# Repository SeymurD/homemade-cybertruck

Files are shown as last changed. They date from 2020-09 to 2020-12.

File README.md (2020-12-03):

# Homemade CyberTruck

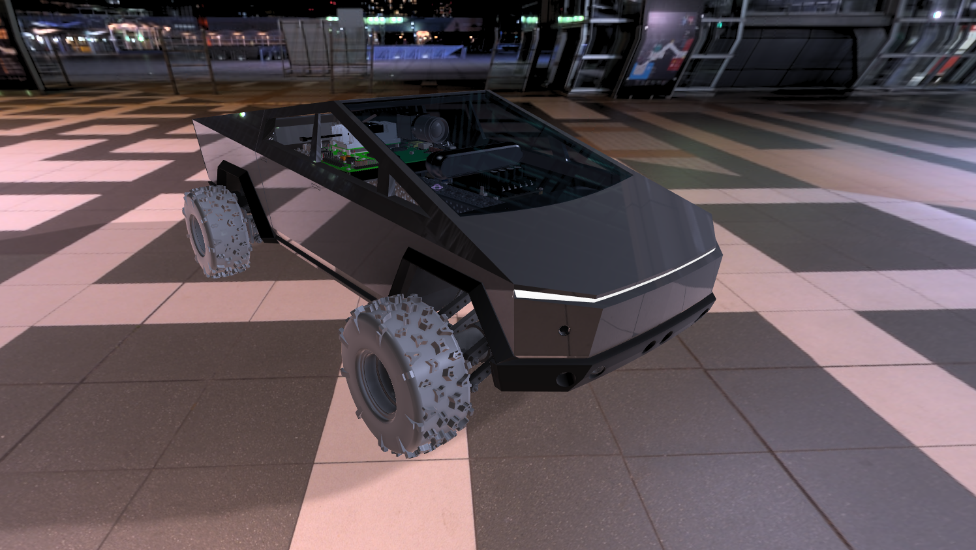
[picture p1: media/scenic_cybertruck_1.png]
CyberTruck Scene 1


### Introduction

The inspiration to build my own small replica of the Cybertruck was fueled by the shear want of trying to create something myself from the ground up and test myself to make something fun and exciting. Having worked on robots for a while in University project teams, I wanted to invest some money into my own maker gear such as a 3D printer, soldering stations, oscilloscope and all the small electronics to make this machine come to life.

The following will be a log of how my work on this progresses on starting from the model crafted in Fusion 360. As of now, I have probably spent around 1 1/2 months sizing, sketching and modelling the truck to be as close in proportion and stance as the real world beast. The greatest challenge in designing the shell of this vehicle is working both with the restrcition on my 3D printer in terms of accuracy, build volume, and part complexity such that I don't have overhangs present in every part. The chassis of was built from aluminium U-Channel beam for structural rigidity and stretches 24" in length. The length is actually closer to 28" when taking into the account the 3D printed rear end. The images below capture the overall design and placement of the interals using some of the rendering tools provided in Fusion360.

| | |
|:---:|:---:|
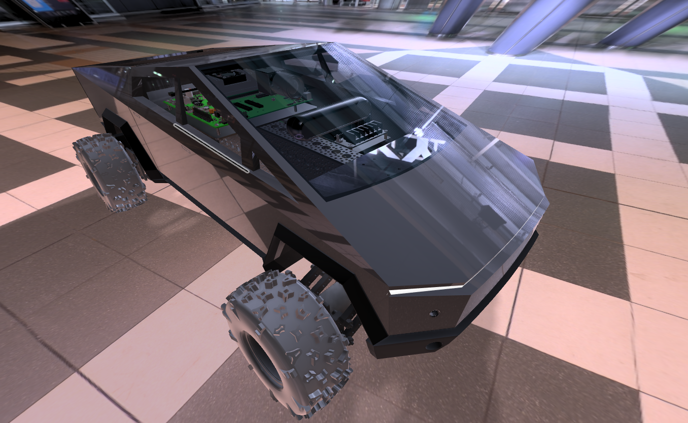
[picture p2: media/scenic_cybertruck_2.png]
cybertruck scene 2
|cybertruck scene 1  Three-Quarter Side View |   Elevated Side View|
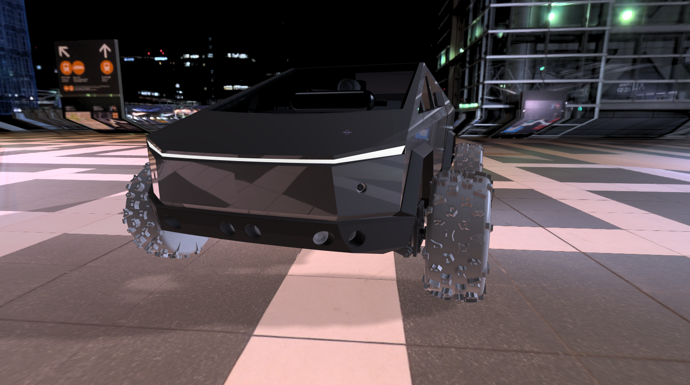
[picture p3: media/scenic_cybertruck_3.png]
cybertruck scene 3
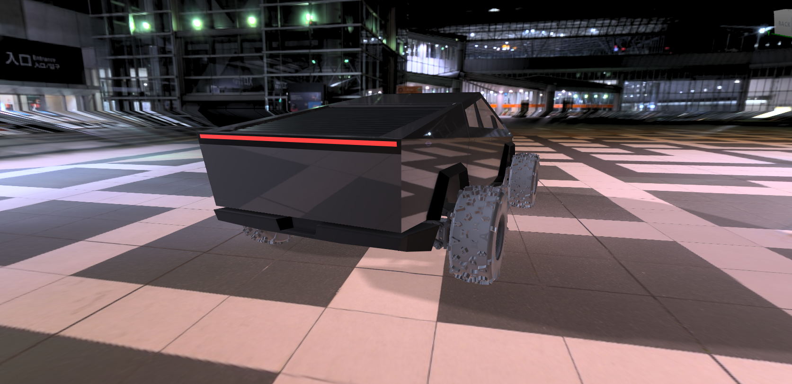
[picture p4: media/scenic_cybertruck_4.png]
cybertruck scene 4
| Front View |   Rear View|

From the Front View image, you may be wondering what some of the little holes are within the front bumper. The smaller holes on the silver portion are angled at 40-degrees and contain RaspberryPi Cam V2 with the base lens and serve as additional sources of imaging data that I can sync with the main FLIR BlackFlyS camera mounted high in the center of the vehicle. Additionally an Intel RealSense depth camera will be mounted near the dash space of the vehicle to provide depth information and once again will be synced with the main camera such that an image from the main camera can have a corresponding depth parameter.

On the lower black front bumper are 6 large holes that correspond to 3 ultrasonic sensors that most electronic hobbyists are familiar with: the HC-SR04 ultrasonic sensor!

The sensors are fitted snug inside the front section by having created a small pocket for each sensor which can be easily accessed in the wheel-well of the vehicle. A solution for keeping the internal wiring clean was also provided by having 3D printed channels run seamlessly within the body of the vehicle and taking advantage of the fact that the core of the vehicle is an aluminium channel.

| | |
|:---:|:---:|
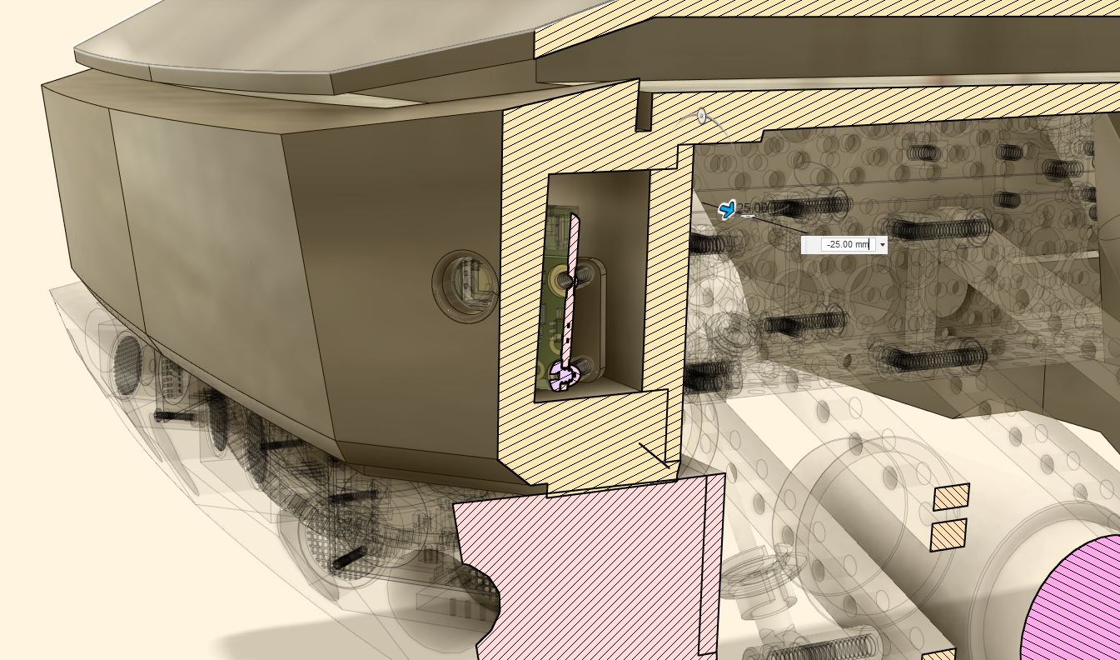
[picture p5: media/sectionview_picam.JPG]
cybertruck picam 1
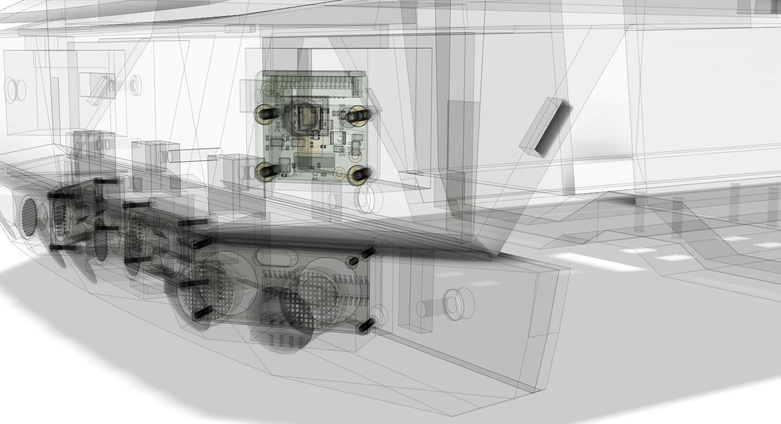
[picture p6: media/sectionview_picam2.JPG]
cybertruck picam 2
|  Cross-Sectional View |   Skeleton/Wireframe View|

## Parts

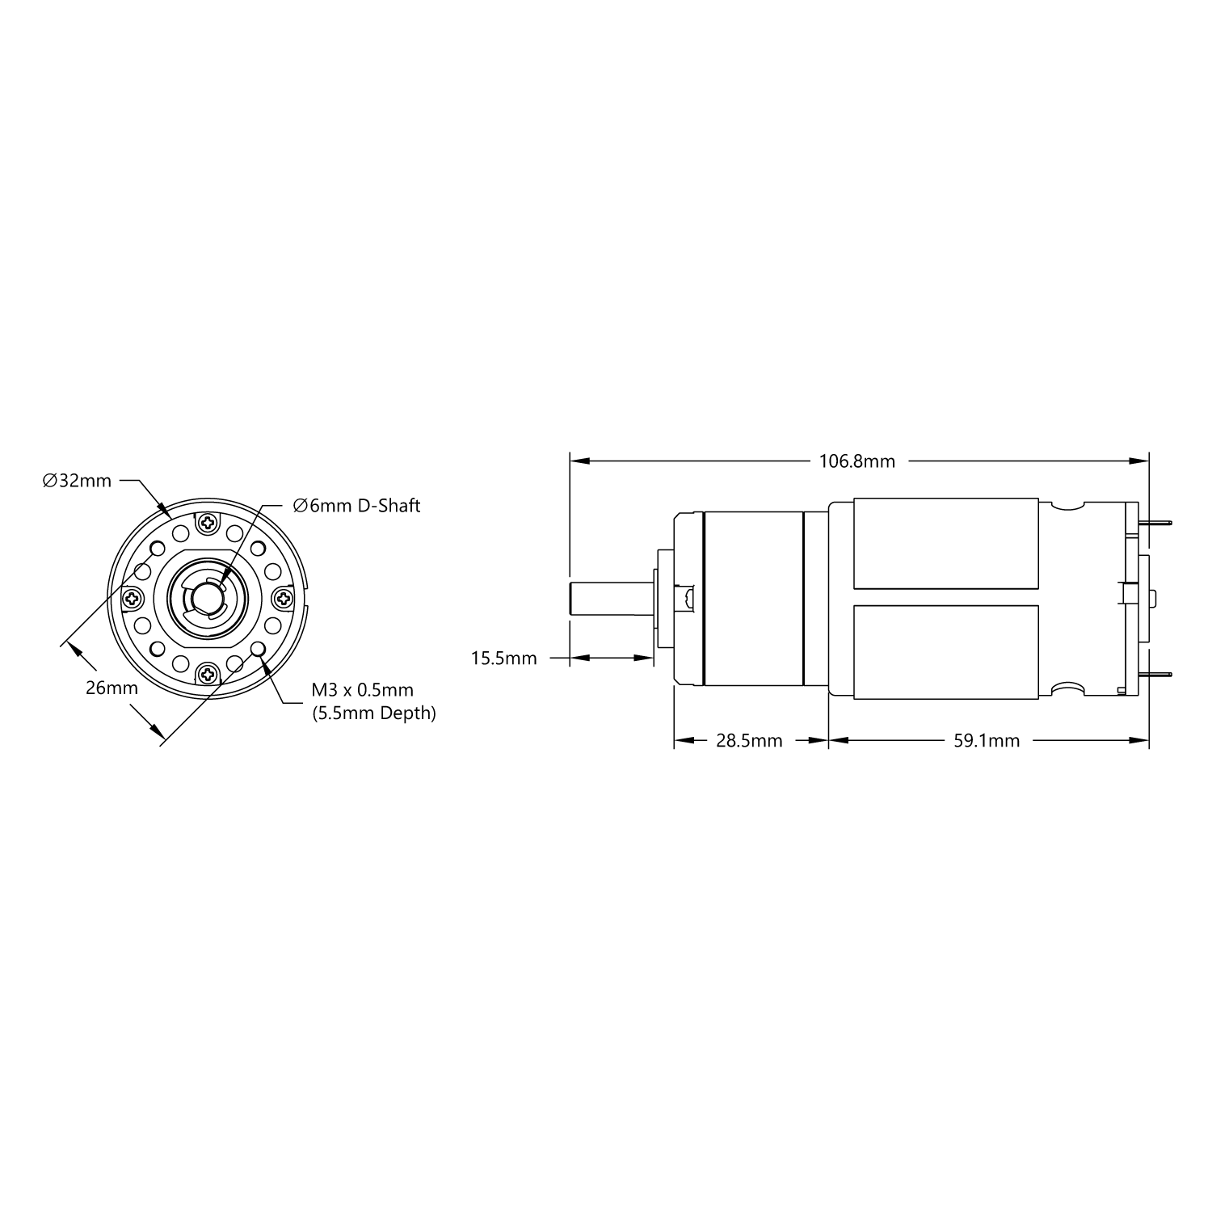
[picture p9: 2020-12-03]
Cybertruck Models/models/Chassis Parts/313 RPM Planetary Motor - CAD Drawing.png

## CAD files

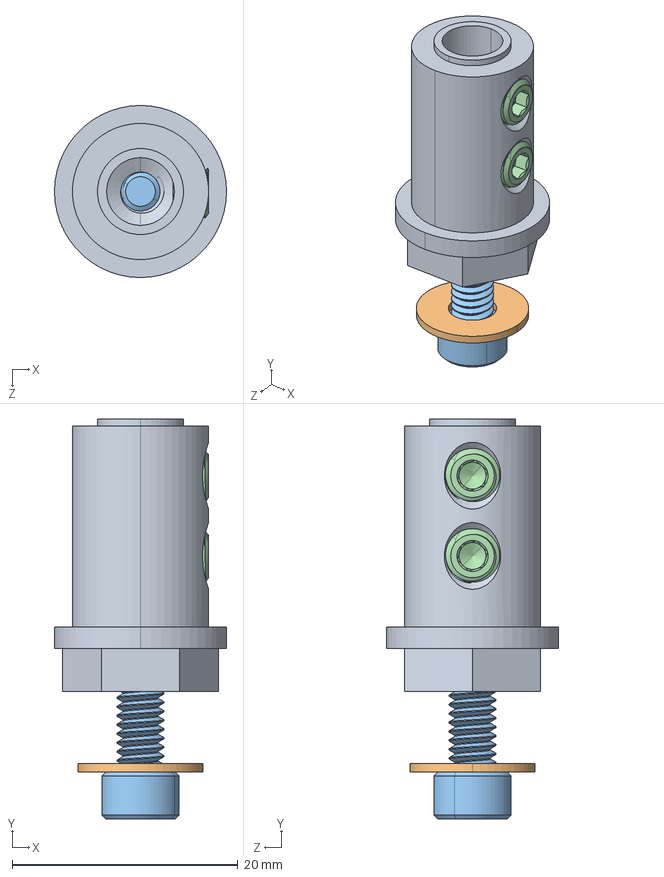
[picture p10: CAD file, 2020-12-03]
Cybertruck Models/models/Chassis Parts/6mm_bore_12mm_hexwheel_mount.STEP
15.2 x 35.4 x 15.2 mm
90126A009_90126A009
90128A194_90128A194
632134_91375A436 x 2

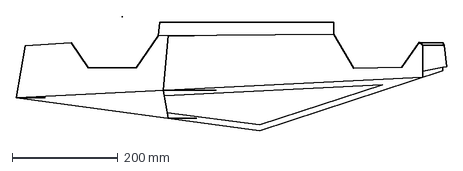
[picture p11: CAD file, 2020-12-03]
Cybertruck Models/models/Exterior Design/diagram_side.dxf
815.0 x 216.4 mm

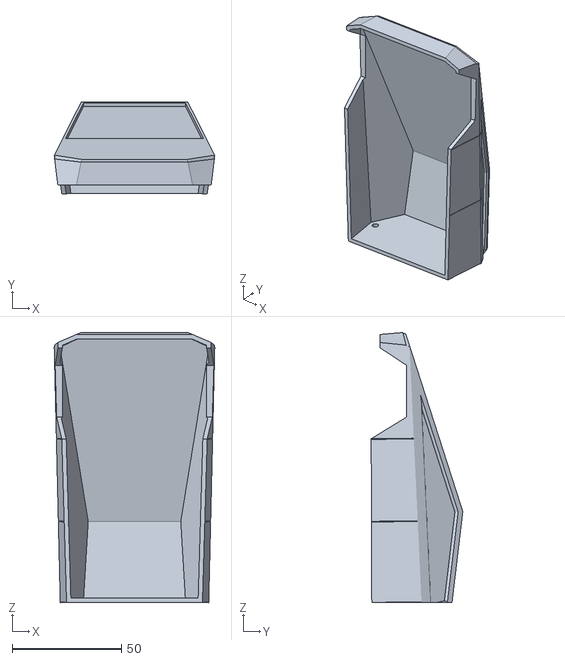
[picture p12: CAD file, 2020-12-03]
Cybertruck Models/models/Exterior Design/files/silver_body_front.stl
73.6 x 42.0 x 123.7

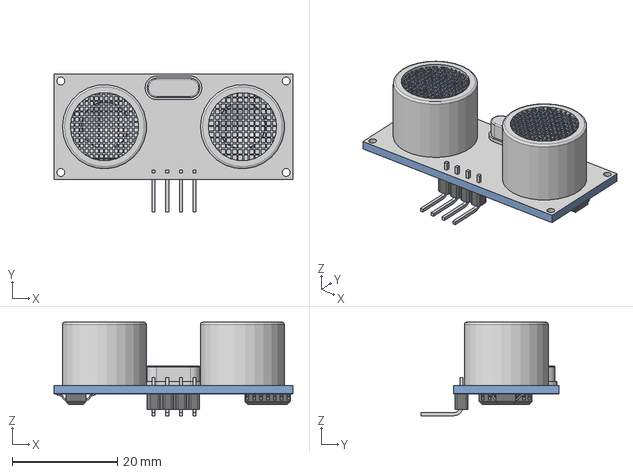
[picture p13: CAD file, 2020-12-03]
Cybertruck Models/models/Hardware Models/HC-SR04-UltrasonicSensor v7.step
45.5 x 26.2 x 17.8 mm

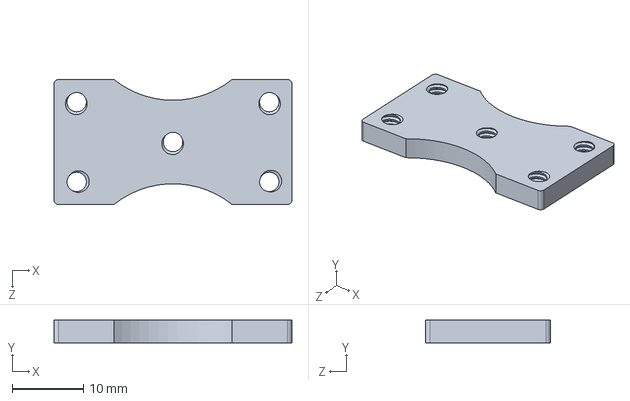
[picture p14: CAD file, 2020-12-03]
Cybertruck Models/models/Chassis Parts/channel_connector_plates.STEP
33.3 x 3.18 x 17.5 mm

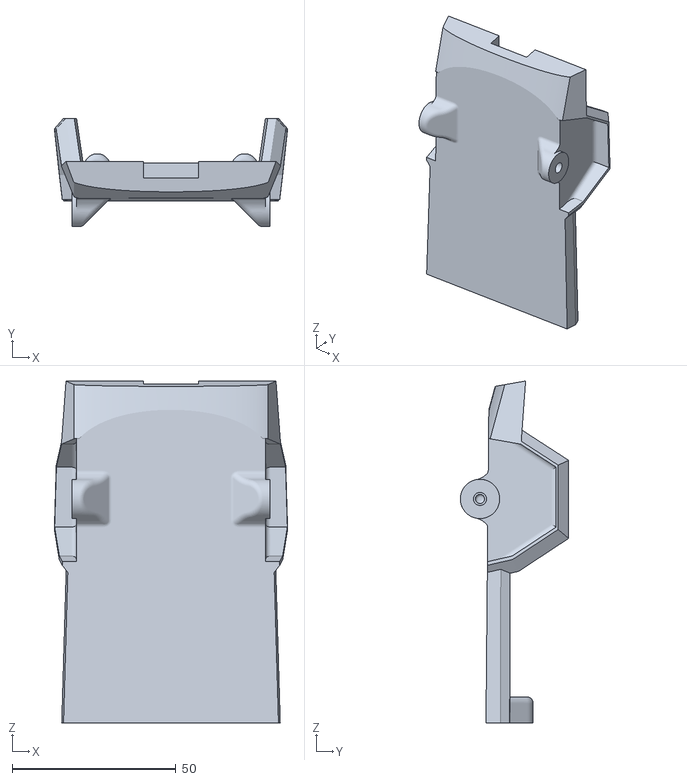
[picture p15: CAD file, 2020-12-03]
Cybertruck Models/models/Exterior Design/files/black_chassis_rear.stl
71.2 x 33.1 x 104.4

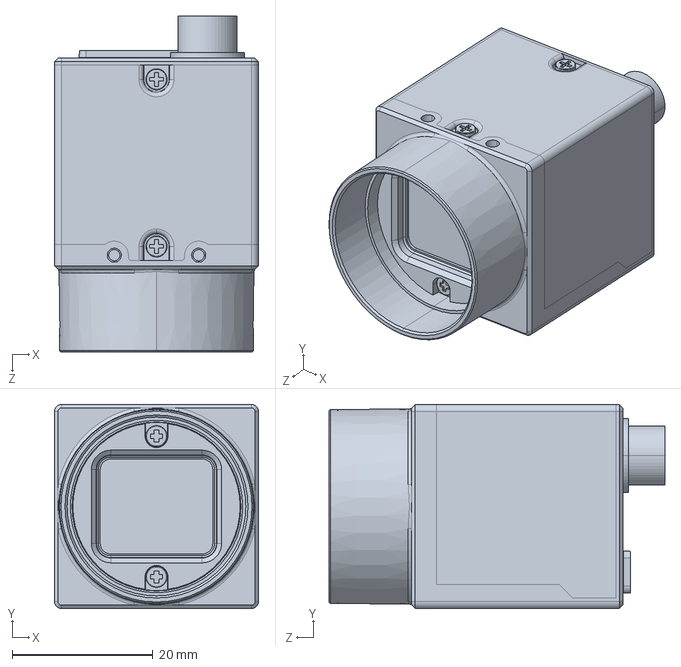
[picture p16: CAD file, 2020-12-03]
Cybertruck Models/models/Hardware Models/FL2-020-R0.STEP
29.0 x 29.0 x 47.8 mm

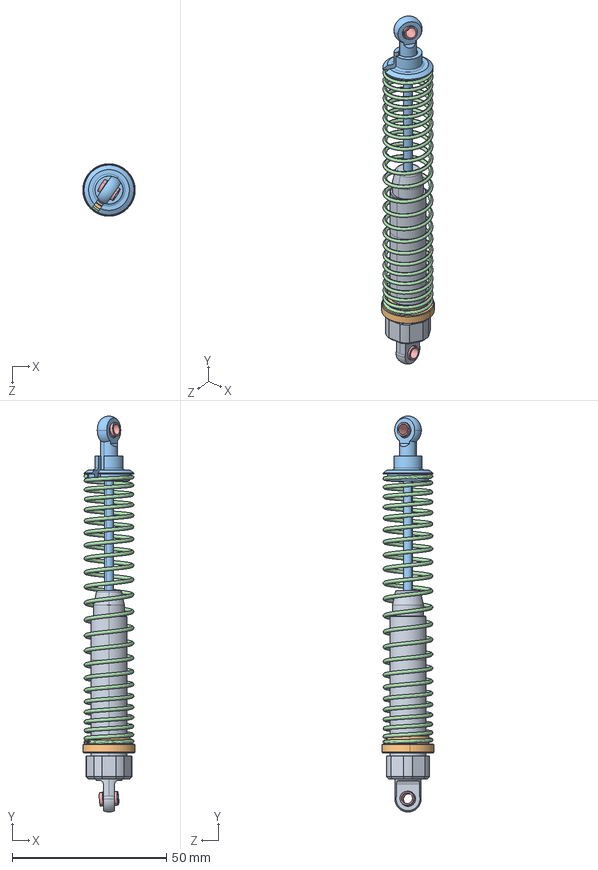
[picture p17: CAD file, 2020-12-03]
Cybertruck Models/models/Chassis Parts/robot_shocks.STEP
17.0 x 128.4 x 17.0 mm
585032 shock body
585032 shock collar
585032 shock shaft
585032 shock spring
585032 shock ball x 2

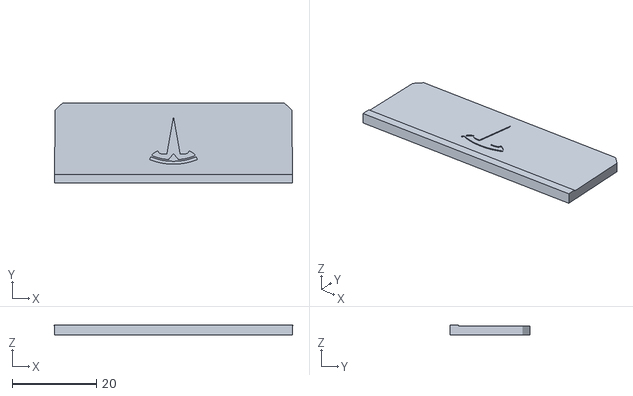
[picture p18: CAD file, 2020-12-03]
Cybertruck Models/models/Exterior Design/files/silver_rear_hatch.stl
56.8 x 19.0 x 2.38

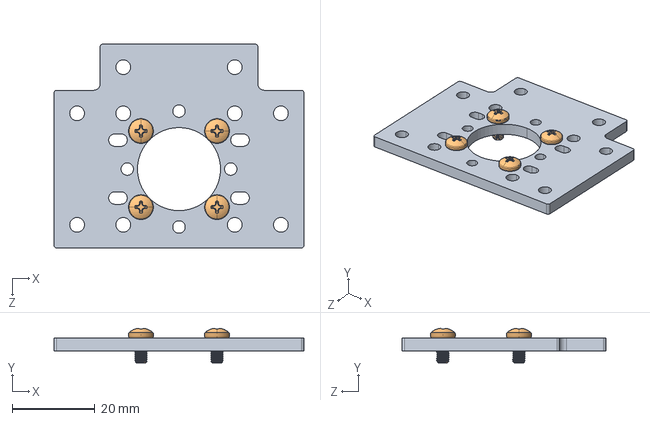
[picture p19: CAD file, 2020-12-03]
Cybertruck Models/models/Chassis Parts/motor_mount_d.STEP
60.4 x 8.34 x 49.3 mm
92005A116_92005A116 x 4

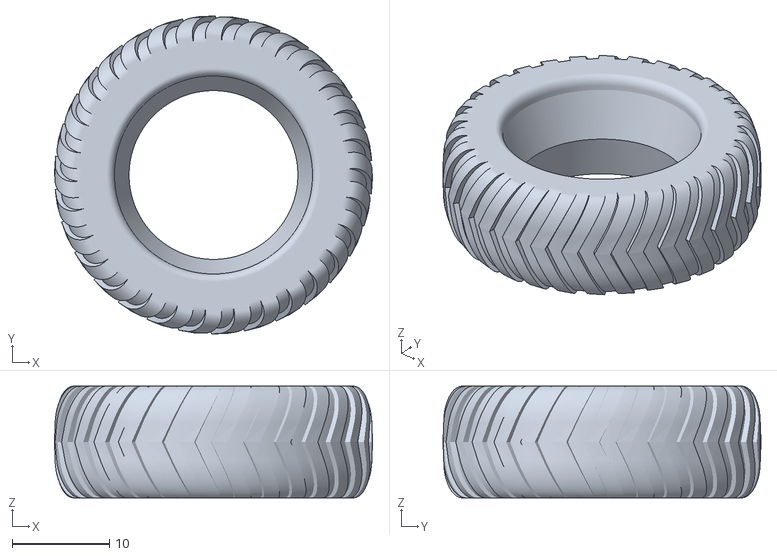
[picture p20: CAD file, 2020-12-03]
Cybertruck Models/models/Exterior Design/files/tpu_tyre_right.stl
32.7 x 32.7 x 11.5

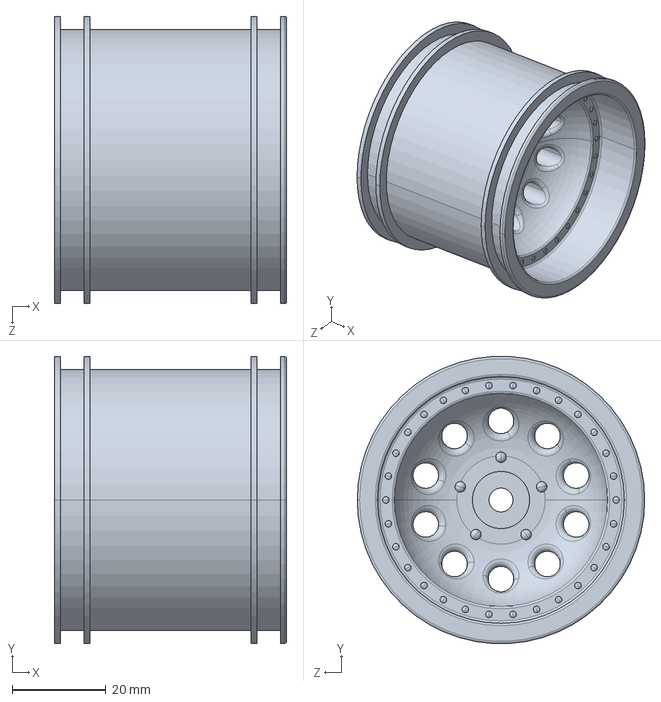
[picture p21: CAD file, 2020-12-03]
Cybertruck Models/models/Chassis Parts/revolver_rims.STEP
49.6 x 61.2 x 61.3 mm

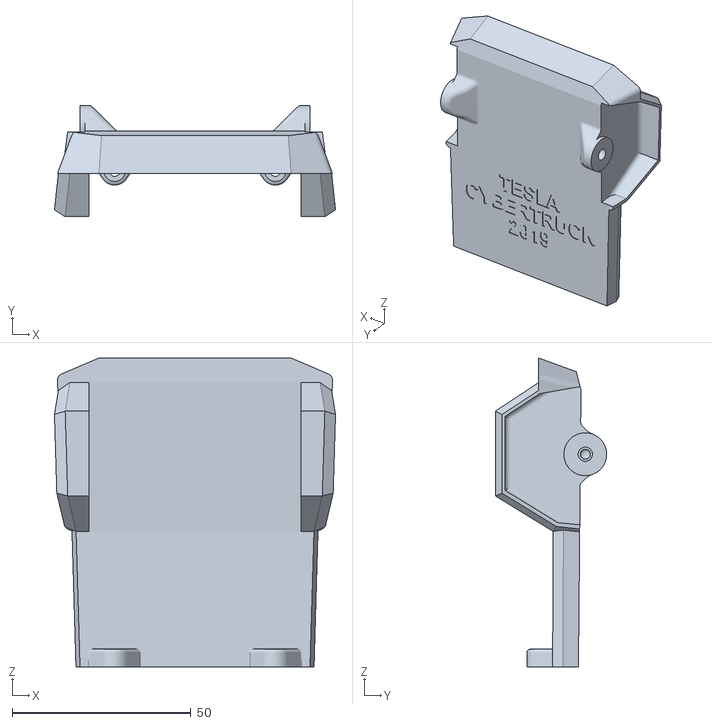
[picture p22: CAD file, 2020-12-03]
Cybertruck Models/models/Exterior Design/files/black_chassis_front.stl
78.7 x 31.2 x 86.5

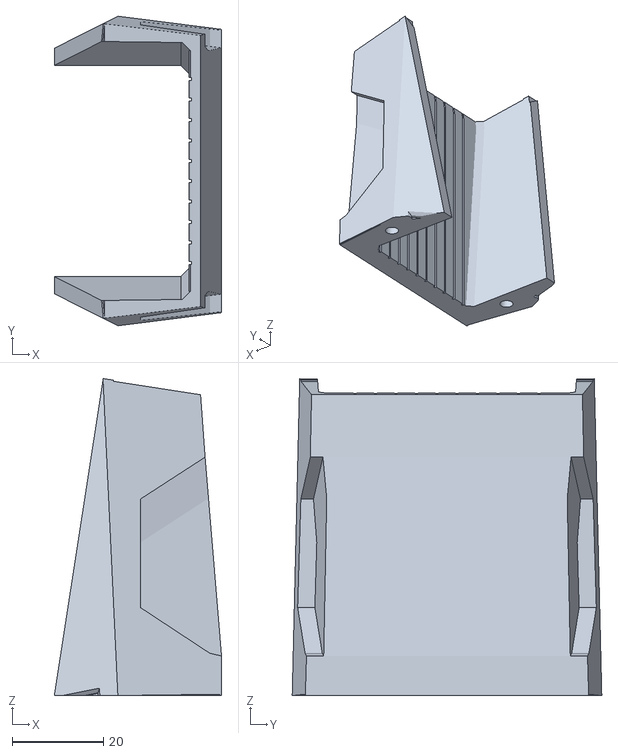
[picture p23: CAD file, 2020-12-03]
Cybertruck Models/models/Exterior Design/files/silver_body_rear.stl
36.8 x 68.0 x 69.6

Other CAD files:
Cybertruck Models/models/Chassis Parts/90_deg_dual_side_mount_d.STEP
Cybertruck Models/models/Exterior Design/files/AT_tyre_right.stl
Cybertruck Models/models/Chassis Parts/hole_aluminum_beams.STEP
Cybertruck Models/models/Exterior Design/files/black_windscreen.stl
Cybertruck Models/models/Chassis Parts/DC Planeary Gear Motor v1.step
Cybertruck Models/models/Chassis Parts/Motor-PlanetaryGear-Encoder.STEP
Cybertruck Models/models/Chassis Parts/standoff_1-4.STEP
Cybertruck Models/models/Chassis Parts/washer.STEP
Cybertruck Models/models/Exterior Design/files/AT_tyre_left.stl
Cybertruck Models/models/Exterior Design/files/black_rim_inside.stl
Cybertruck Models/models/Exterior Design/files/black_rim_outside.stl
Cybertruck Models/models/Exterior Design/files/black_window_left.stl
Cybertruck Models/models/Exterior Design/files/black_window_right.stl
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

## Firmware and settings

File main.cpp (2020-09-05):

#include <stdio.h>
#include <unistd.h>       // Used for UART
#include <sys/fcntl.h>    // Used for UART
#include <termios.h>      // Used for UART
#include <string>
#include <sstream>
#include <iostream>       // User input for motors

using namespace std;

// Define Constants
const char *uart_target = "/dev/ttyTHS2";
#define     NSERIAL_CHAR   256
#define     VMINX          1
#define     BAUDRATE       B115200

int main()
{
    printf("-----------------Program Start-----------------\n\n");

    int ii, jj, kk;

    // SETUP SERIAL WORLD
    int fid = -1;
    struct termios  port_options;   // Create the structure                          

    tcgetattr(fid, &port_options);  // Get the current attributes of the Serial port 

	
    //------------------------------------------------
    //  OPEN THE UART
    //------------------------------------------------
    // The flags (defined in fcntl.h):
    //	Access modes (use 1 of these):
    //		O_RDONLY - Open for reading only.
    //		O_RDWR   - Open for reading and writing.
    //		O_WRONLY - Open for writing only.
    //	        O_NDELAY / O_NONBLOCK (same function) 
    //               - Enables nonblocking mode. When set read requests on the file can return immediately with a failure status
    //                 if there is no input immediately available (instead of blocking). Likewise, write requests can also return
    //	               immediately with a failure status if the output can't be written immediately.
    //                 Caution: VMIN and VTIME flags are ignored if O_NONBLOCK flag is set.
    //	        O_NOCTTY - When set and path identifies a terminal device, open() shall not cause the terminal device to become the 
    //                     controlling terminal for the process.fid = open("/dev/ttyTHS1", O_RDWR | O_NOCTTY | O_NDELAY);		
    //Open in non blocking read/write mode

    fid = open(uart_target, O_WRONLY | O_NOCTTY );

    tcflush(fid, TCIFLUSH);
    tcflush(fid, TCIOFLUSH);
 	
    usleep(1000000);  // 1 sec delay

    if (fid == -1)
	{
		printf("Error - Unable to open UART.  Ensure it is not in use by another application\n");
	}
	
    //------------------------------------------------
    // CONFIGURE THE UART
    //------------------------------------------------
    // flags defined in /usr/include/termios.h - see http://pubs.opengroup.org/onlinepubs/007908799/xsh/termios.h.html
    //	Baud rate:
    //         - B1200, B2400, B4800, B9600, B19200, B38400, B57600, B115200, 
    //           B230400, B460800, B500000, B576000, B921600, B1000000, B1152000, 
    //           B1500000, B2000000, B2500000, B3000000, B3500000, B4000000
    //	CSIZE: - CS5, CS6, CS7, CS8
    //	CLOCAL - Ignore modem status lines
    //	CREAD  - Enable receiver
    //	IGNPAR = Ignore characters with parity errors
    //	ICRNL  - Map CR to NL on input (Use for ASCII comms where you want to auto correct end of line characters - don't use for bianry comms!)
    //	PARENB - Parity enable
    //	PARODD - Odd parity (else even)

    port_options.c_cflag &= ~PARENB;            // Disables the Parity Enable bit(PARENB),So No Parity   
    port_options.c_cflag &= ~CSTOPB;            // CSTOPB = 2 Stop bits,here it is cleared so 1 Stop bit 
    port_options.c_cflag &= ~CSIZE;	        // Clears the mask for setting the data size             
    port_options.c_cflag |=  CS8;               // Set the data bits = 8                                 	 
    port_options.c_cflag &= ~CRTSCTS;           // No Hardware flow Control                         
    port_options.c_cflag |=  CREAD | CLOCAL;                  // Enable receiver,Ignore Modem Control lines       				
    port_options.c_iflag &= ~(IXON | IXOFF | IXANY);          // Disable XON/XOFF flow control both input & output
    port_options.c_iflag &= ~(ICANON | ECHO | ECHOE | ISIG);  // Non Cannonical mode                            
    port_options.c_oflag &= ~OPOST;                           // No Output Processing

    //port_options.c_lflag = 0;               //  enable raw input instead of canonical,
 		
    //port_options.c_cc[VMIN]  = VMINX;       // Read at least 1 character
    //port_options.c_cc[VTIME] = 0;           // Wait indefinetly 
		
    //cfsetispeed(&port_options,BAUDRATE);    // Set Read  Speed 
    cfsetospeed(&port_options,BAUDRATE);    // Set Write Speed 

    // Set the attributes to the termios structure
    int att = tcsetattr(fid, TCSANOW, &port_options);

    if (att != 0 )
    {
        printf("\nERROR in Setting port attributes");
    }
    else
    {
        printf("\nSERIAL Port Good to Go.\n");
    }

    // Flush Buffers
    tcflush(fid, TCIFLUSH);
    tcflush(fid, TCIOFLUSH);

    usleep(500000);   // 0.5 sec delay

//--------------------------------------------------------------
    // TRANSMITTING BYTES
    //--------------------------------------------------------------
    unsigned char tx_buffer[20];
    unsigned char *p_tx_buffer;
    int count = 0;
    int goodTX = 0;
	
    // Send dummy byte
    printf("Sending dummy byte 0x80");

    p_tx_buffer = &tx_buffer[0];
    *p_tx_buffer++ = 0x80;
    count = write(fid, &tx_buffer[0], (p_tx_buffer - &tx_buffer[0]));
    usleep(1000000);

    p_tx_buffer = &tx_buffer[0]; // move pointer back to start
    // Front Controller
    *p_tx_buffer++ = 0x55;	 // Header - send decimal 85 (0x55)
    *p_tx_buffer++ = 0x00;	 // Channel & Address - 0b0000 0000 - turn on left motor @ ID: 000
    *p_tx_buffer++ = 0xA0;	 // Command - set speed to 160 (0xA0) centered around 127
    *p_tx_buffer++ = 0x55 + 0x00 + 0xA0;	 // Checksum - result of Header + Address + Command
    // Back Controller
    *p_tx_buffer++ = 0x55;	 // Header - send decimal 85 (0x55)
    *p_tx_buffer++ = 0x01;	 // Channel & Address - 0b0000 0001 - turn on left motor @ ID: 001
    *p_tx_buffer++ = 0xA0;	 // Command - set speed to 160 (0xA0) centered around 127
    *p_tx_buffer++ = 0x55 + 0x01 + 0xA0;	 // Checksum - result of Header + Address + Command
    
    printf("fid 1=%d\n", fid );
	
	if (fid != -1)
	{	
		count = write(fid, &tx_buffer[0], (p_tx_buffer - &tx_buffer[0])); //Filestream, bytes to write, number of bytes to write

        	usleep(1000);   // .001 sec delay

        	printf("Count = %d\n", count);
		printf("Sucessful Transmissions: %d\n", goodTX);

		if (count < 0)  printf("UART TX error\n");
	}

    	usleep(1000000);  // 1 sec delay
    

/*   
    string inputUser;
    int speedChange;
    int dir;
    cout << "New speed value (0-63): ";
    getline (cin, inputUser);
    stringstream(inputUser) >> speedChange;
    cout << "Direction value (0,1): ";
    getline (cin, inputUser);
    stringstream(inputUser) >> dir;
    printf("You entered: %d\n", speedChange);
    printf("You entered: %d\n", dir);
    
    unsigned char new_buffer[0];
    new_buffer[0] = speedChange & 0xFF;
    if (dir == 1) new_buffer[0] |= 0x40;    
    printf("%x\n", new_buffer[0]);
    
    p_tx_buffer = &tx_buffer[0];

    *p_tx_buffer++ = new_buffer[0];

    count = write(fid, &tx_buffer[0], (p_tx_buffer - &tx_buffer[0]));
    usleep(1000);   // .001 sec delay
*/


/*
//--------------------------------------------------------------
    // RECEIVING BYTES - AND BUILD MESSAGE RECEIVED
    //--------------------------------------------------------------
    unsigned char rx_buffer[VMINX];
    unsigned char serial_message[NSERIAL_CHAR];
    bool          pickup = true;
    int           rx_length;
    int           nread = 0;    

	tcflush(fid, TCIOFLUSH);

    usleep(1000);   // .001 sec delay

    printf("Ready to receive message.\n");

for (ii=0; ii<NSERIAL_CHAR; ii++)  serial_message[ii]=' ';

	while (pickup && fid != -1)
	{
        nread++;

        rx_length = read(fid, (void*)rx_buffer, VMINX);   // Filestream, buffer to store in, number of bytes to read (max)

        printf("Event %d, rx_length=%d, Read=%s\n",  nread, rx_length, rx_buffer );

		if (rx_length < 0)
		{
			//An error occured (will occur if there are no bytes)
		}

		if (rx_length == 0)
		{
			//No data waiting
		}
		
        if (rx_length>=0)
		{
            if (nread<=NSERIAL_CHAR)   serial_message[nread-1] = rx_buffer[0];   // Build message 1 character at a time

            if (rx_buffer[0]=='#')   pickup=false;                               // # symbol is terminator
		}
	}

    printf("\nMessage Received: %s", serial_message);
*/
//-------------------------------------------
    //  CLOSE THE SERIAL PORT
    //-------------------------------------------
    close(fid);

printf("\n\nGoodbye World\n\n");

}
